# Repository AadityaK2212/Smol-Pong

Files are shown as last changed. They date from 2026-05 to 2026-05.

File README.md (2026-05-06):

# Smol-Pong
It is a mini console that can run a 2 player pong game using a coin cell battery and a 8X8 LED grid. ioriginally saw someoemake a smal buiness card that can play video games, so I elaborated off of that and made it to only play pong I also created one for flappy bird. It runs on an ATtiny 1616 Microcontroller.






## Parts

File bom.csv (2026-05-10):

Designator | Footprint | Quantity | Value | LCSC Part #
BT1 | BatteryHolder_Keystone_1057_1x2032 | 1 | Battery_Cell
D1, D10, D11, D12, D13, D14, D15, D16, D17, D18, D19, D2, D20, D21, D22, D23, D24, D25, D26, D27, D28, D29, D3, D30, D31, D32, D33, D34, D35, D36, D37, D38, D39, D4, D40, D41, D42, D43, D44, D45, D46, D47, D48, D49, D5, D50, D51, D52, D53, D54, D55, D56, D57, D58, D59, D6, D60, D61, D62, D63, D64, D7, D8, D9 | 0603 | 64 | LED
R1, R13, R14, R15, R16, R17, R18, R19, R2, R20, R3, R4, R5, R6, R7, R8 | 0603 | 16 | 100 Ω
SW1 | SW_SPST_TL3342 | 1 | SW_P1_UP
U1 | VQFN-20-1EP_3x3mm_P0.4mm_EP1.7x1.7mm | 1 | ATtiny1616-M

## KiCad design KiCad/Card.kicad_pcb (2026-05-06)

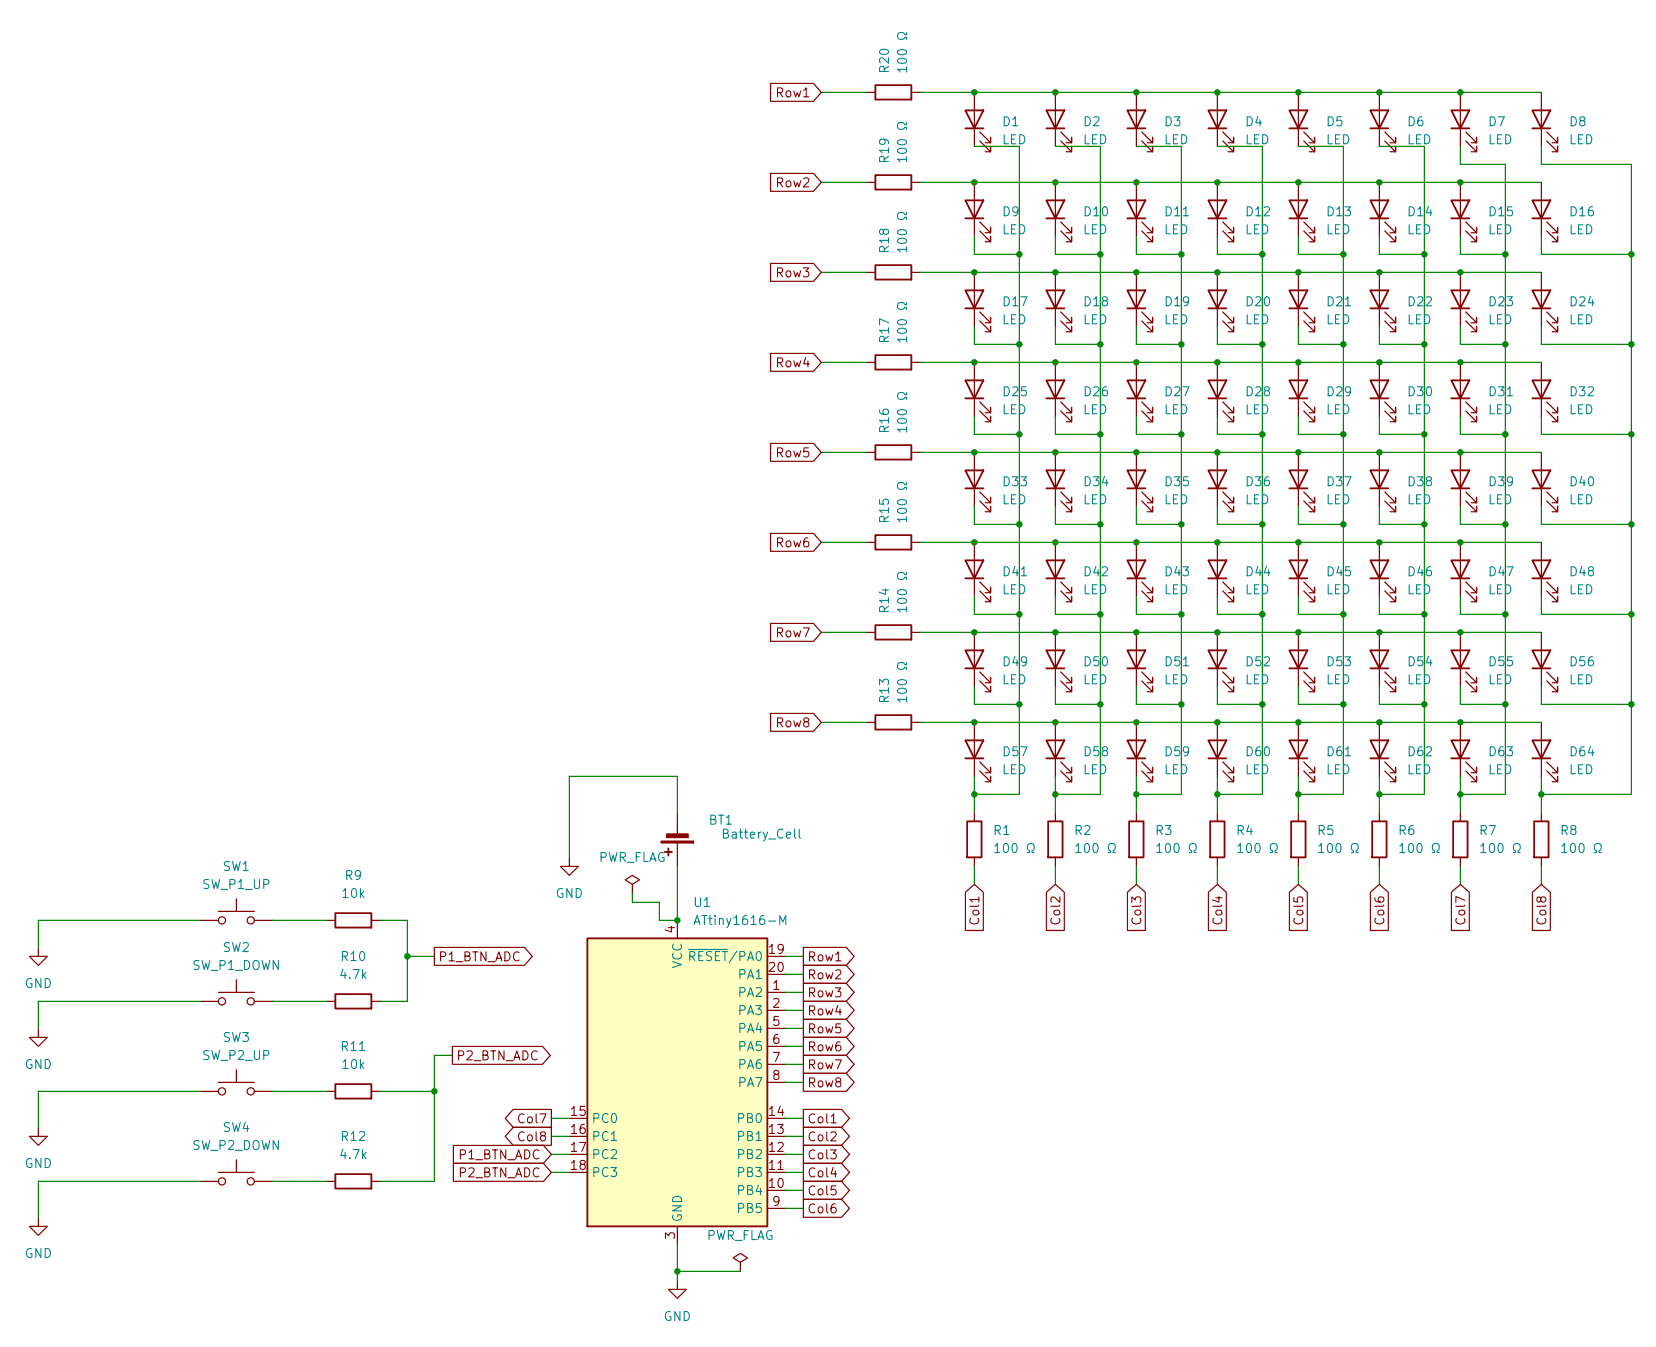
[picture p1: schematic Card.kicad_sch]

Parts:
BT1: Battery_Cell; BatteryHolder_Keystone_1057_1x2032
D1, D2, D3, D4, D5, D6, D7, D8, D9, D10, D11, D12, D13, D14, D15, D16, D17, D18, D19, D20, D21, D22, D23, D24, D25, D26, D27, D28, D29, D30, D31, D32, D33, D34, D35, D36, D37, D38, D39, D40, D41, D42, D43, D44, D45, D46, D47, D48, D49, D50, D51, D52, D53, D54, D55, D56, D57, D58, D59, D60, D61, D62, D63, D64: LED; LED_0603_1608Metric
R1, R2, R3, R4, R5, R6, R7, R8, R13, R14, R15, R16, R17, R18, R19, R20: 100 Ω; R_0603_1608Metric
R9, R11: 10k; R_0603_1608Metric
R10, R12: 4.7k; R_0603_1608Metric
SW1: SW_P1_UP; SW_SPST_TL3342
SW2: SW_P1_DOWN; SW_SPST_TL3342
SW3: SW_P2_UP; SW_SPST_TL3342
SW4: SW_P2_DOWN; SW_SPST_TL3342
U1: ATtiny1616-M; VQFN-20-1EP_3x3mm_P0.4mm_EP1.7x1.7mm

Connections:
Col1: R1.2, U1.14 (PB0)
Col2: R2.2, U1.13 (PB1)
Col3: R3.2, U1.12 (PB2)
Col4: R4.2, U1.11 (PB3)
Col5: R5.2, U1.10 (PB4)
Col6: R6.2, U1.9 (PB5)
Col7: R7.2, U1.15 (PC0)
Col8: R8.2, U1.16 (PC1)
GND: BT1.2 (-), SW1.1, SW2.1, SW3.1, SW4.1, U1.3 (GND), U1.21 (GND)
unnamed: BT1.1 (+), U1.4 (VCC)
unnamed: D1.2 (A), D2.2 (A), D3.2 (A), D4.2 (A), D5.2 (A), D6.2 (A), D7.2 (A), D8.2 (A), R20.2
unnamed: D1.1 (K), D9.1 (K), D17.1 (K), D25.1 (K), D33.1 (K), D41.1 (K), D49.1 (K), D57.1 (K), R1.1
unnamed: D9.2 (A), D10.2 (A), D11.2 (A), D12.2 (A), D13.2 (A), D14.2 (A), D15.2 (A), D16.2 (A), R19.2
unnamed: D2.1 (K), D10.1 (K), D18.1 (K), D26.1 (K), D34.1 (K), D42.1 (K), D50.1 (K), D58.1 (K), R2.1
unnamed: D3.1 (K), D11.1 (K), D19.1 (K), D27.1 (K), D35.1 (K), D43.1 (K), D51.1 (K), D59.1 (K), R3.1
unnamed: D4.1 (K), D12.1 (K), D20.1 (K), D28.1 (K), D36.1 (K), D44.1 (K), D52.1 (K), D60.1 (K), R4.1
unnamed: D5.1 (K), D13.1 (K), D21.1 (K), D29.1 (K), D37.1 (K), D45.1 (K), D53.1 (K), D61.1 (K), R5.1
unnamed: D6.1 (K), D14.1 (K), D22.1 (K), D30.1 (K), D38.1 (K), D46.1 (K), D54.1 (K), D62.1 (K), R6.1
unnamed: D7.1 (K), D15.1 (K), D23.1 (K), D31.1 (K), D39.1 (K), D47.1 (K), D55.1 (K), D63.1 (K), R7.1
unnamed: D8.1 (K), D16.1 (K), D24.1 (K), D32.1 (K), D40.1 (K), D48.1 (K), D56.1 (K), D64.1 (K), R8.1
unnamed: D17.2 (A), D18.2 (A), D19.2 (A), D20.2 (A), D21.2 (A), D22.2 (A), D23.2 (A), D24.2 (A), R18.2
unnamed: D25.2 (A), D26.2 (A), D27.2 (A), D28.2 (A), D29.2 (A), D30.2 (A), D31.2 (A), D32.2 (A), R17.2
unnamed: D33.2 (A), D34.2 (A), D35.2 (A), D36.2 (A), D37.2 (A), D38.2 (A), D39.2 (A), D40.2 (A), R16.2
unnamed: D41.2 (A), D42.2 (A), D43.2 (A), D44.2 (A), D45.2 (A), D46.2 (A), D47.2 (A), D48.2 (A), R15.2
unnamed: D49.2 (A), D50.2 (A), D51.2 (A), D52.2 (A), D53.2 (A), D54.2 (A), D55.2 (A), D56.2 (A), R14.2
unnamed: D57.2 (A), D58.2 (A), D59.2 (A), D60.2 (A), D61.2 (A), D62.2 (A), D63.2 (A), D64.2 (A), R13.2
unnamed: R9.1, SW1.2
unnamed: R10.1, SW2.2
unnamed: R11.1, SW3.2
unnamed: R12.1, SW4.2
P1_BTN_ADC: R9.2, R10.2, U1.17 (PC2)
P2_BTN_ADC: R11.2, R12.2, U1.18 (PC3)
Row1: R20.1, U1.19 (~RESET/PA0)
Row2: R19.1, U1.20 (PA1)
Row3: R18.1, U1.1 (PA2)
Row4: R17.1, U1.2 (PA3)
Row5: R16.1, U1.5 (PA4)
Row6: R15.1, U1.6 (PA5)
Row7: R14.1, U1.7 (PA6)
Row8: R13.1, U1.8 (PA7)

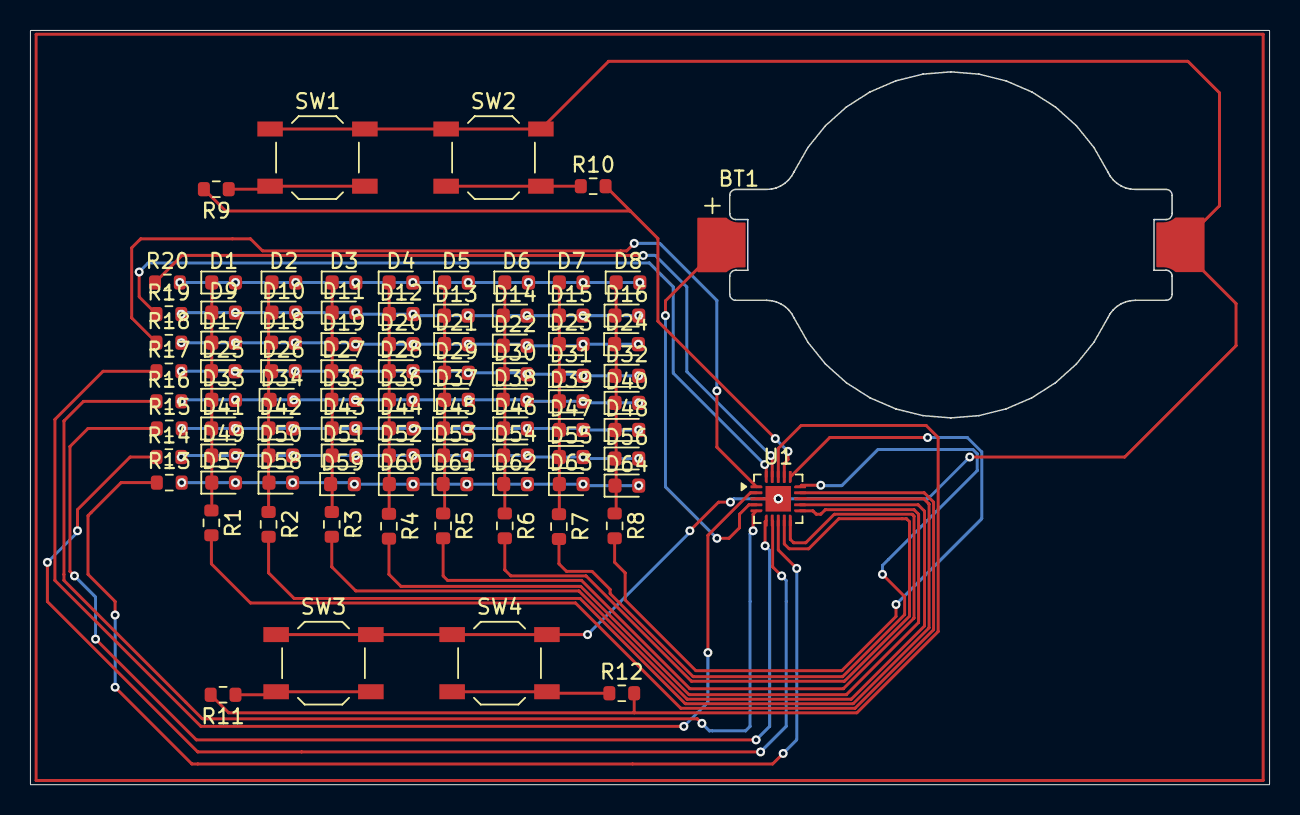
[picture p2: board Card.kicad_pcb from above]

Board: 2 copper layers, 82.4 x 50.1 mm, 90 parts (0 on the bottom side), 40 nets.

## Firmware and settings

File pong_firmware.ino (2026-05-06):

// Pong on an 8x8 LED matrix, driven by an ATtiny1616.
// Two players, two buttons each (UP / DOWN), wired as an analog
// resistor ladder so each player only burns one MCU pin.
//
// Hardware notes (from the schematic):
//   - Rows  -> PA0..PA7  (Row1..Row8) -- these are the LED CATHODES
//   - Cols  -> PB0..PB5  (Col1..Col6)
//             PC0 -> Col7
//             PC1 -> Col8                -- columns are the LED ANODES
//   - PC2   -> P1 button ADC node
//   - PC3   -> P2 button ADC node
//
// To light pixel (row, col): drive that column HIGH, that row LOW,
// every other row Hi-Z (or HIGH), every other column LOW.
// We multiplex one column at a time at a few hundred Hz so the whole
// frame looks stable to the eye.
//
// Button decoding:
//   Idle (nothing pressed) the ADC pin floats up to ~VCC through the
//   internal pull-up. Pressing UP shorts it through 10k to GND, pressing
//   DOWN shorts it through 4.7k to GND. With the ATtiny's ~30-50k
//   internal pull-up that gives roughly:
//       idle  -> ~1023
//       UP    -> ~250-350
//       DOWN  -> ~120-180
//   We just pick two thresholds with comfortable margin.

#include <Arduino.h>

// ---------- pin map ----------
static const uint8_t ROW_PINS[8] = {
  PIN_PA0, PIN_PA1, PIN_PA2, PIN_PA3,
  PIN_PA4, PIN_PA5, PIN_PA6, PIN_PA7
};
static const uint8_t COL_PINS[8] = {
  PIN_PB0, PIN_PB1, PIN_PB2, PIN_PB3,
  PIN_PB4, PIN_PB5, PIN_PC0, PIN_PC1
};

static const uint8_t P1_ADC_PIN = PIN_PC2;
static const uint8_t P2_ADC_PIN = PIN_PC3;

// ---------- ADC thresholds for the resistor-ladder buttons ----------
// Anything below DOWN_MAX -> down, between -> up, above -> nothing.
// Tweak if your particular pull-up reads differently.
static const uint16_t DOWN_MAX = 220;   // 4.7k pull-down
static const uint16_t UP_MAX   = 500;   // 10k  pull-down
// (>UP_MAX is treated as "no press")

// ---------- framebuffer ----------
// frame[col] is a bitmask of which rows are lit in that column.
// Bit r set -> row r is lit when we light up that column.
static volatile uint8_t frame[8];

// ---------- game state ----------
static const uint8_t PADDLE_LEN = 3;     // pixels tall
static int8_t  p1_y = 3;                 // top row of P1 paddle (col 0)
static int8_t  p2_y = 3;                 // top row of P2 paddle (col 7)

// Ball, stored in 1/8-pixel units so we can have fractional speeds.
// A whole pixel is 8 sub-units.
static int16_t ball_x = 4 * 8;
static int16_t ball_y = 4 * 8;
static int16_t ball_vx = -2;             // sub-units per tick
static int16_t ball_vy =  1;

static uint8_t p1_score = 0;
static uint8_t p2_score = 0;
static const uint8_t WIN_SCORE = 5;

// ---------- timing ----------
static uint32_t last_tick_ms     = 0;
static uint32_t last_input_ms    = 0;
static uint32_t last_repeat_ms[2]= {0, 0};
static const uint16_t TICK_MS    = 90;   // game tick (ball moves about 11 Hz)
static const uint16_t INPUT_MS   = 25;   // poll buttons ~40 Hz
static const uint16_t REPEAT_MS  = 70;   // hold-to-move repeat rate

enum GameMode : uint8_t {
  MODE_PLAY,
  MODE_WIN_P1,
  MODE_WIN_P2,
  MODE_RESET_HOLD
};
static uint8_t mode = MODE_PLAY;
static uint32_t mode_started_ms = 0;

// ===================================================================
// LED MATRIX
// ===================================================================
//
// We park every pin as INPUT (Hi-Z) at start and only drive the pins
// for the column that's currently being shown. That keeps unused
// LEDs fully dark and avoids fighting the ADC pins.

static void matrix_init() {
  for (uint8_t i = 0; i < 8; i++) {
    pinMode(ROW_PINS[i], INPUT);
    pinMode(COL_PINS[i], INPUT);
  }
  for (uint8_t i = 0; i < 8; i++) frame[i] = 0;
}

// Show a single column for a brief moment, then turn it back off.
static void show_column(uint8_t c) {
  uint8_t mask = frame[c];

  // Set every row that should be lit to OUTPUT-LOW (sink current),
  // others to INPUT (Hi-Z).
  for (uint8_t r = 0; r < 8; r++) {
    if (mask & (1 << r)) {
      pinMode(ROW_PINS[r], OUTPUT);
      digitalWrite(ROW_PINS[r], LOW);
    } else {
      pinMode(ROW_PINS[r], INPUT);
    }
  }

  // Drive the chosen column HIGH (source current).
  pinMode(COL_PINS[c], OUTPUT);
  digitalWrite(COL_PINS[c], HIGH);

  // Hold it on. Longer = brighter, but eats CPU time.
  delayMicroseconds(700);

  // Turn the column back off and release the rows.
  digitalWrite(COL_PINS[c], LOW);
  pinMode(COL_PINS[c], INPUT);
  for (uint8_t r = 0; r < 8; r++) {
    if (mask & (1 << r)) pinMode(ROW_PINS[r], INPUT);
  }
}

// Run one full pass over all 8 columns. Call this in a tight loop.
static void refresh_once() {
  for (uint8_t c = 0; c < 8; c++) show_column(c);
}

// Helpers used by the game logic to draw into the framebuffer.
static inline void fb_clear() {
  for (uint8_t c = 0; c < 8; c++) frame[c] = 0;
}
static inline void fb_set(int8_t x, int8_t y) {
  if (x < 0 || x > 7 || y < 0 || y > 7) return;
  frame[x] |= (uint8_t)(1 << y);
}

// ===================================================================
// BUTTONS
// ===================================================================

enum BtnState : uint8_t { BTN_NONE = 0, BTN_UP = 1, BTN_DOWN = 2 };

static uint8_t read_button(uint8_t pin) {
  uint16_t v = analogRead(pin);
  if (v < DOWN_MAX) return BTN_DOWN;
  if (v < UP_MAX)   return BTN_UP;
  return BTN_NONE;
}

static void buttons_init() {
  // Internal pull-up makes the resistor-ladder math work and gives us
  // a clean "nothing pressed -> full scale" reading.
  pinMode(P1_ADC_PIN, INPUT_PULLUP);
  pinMode(P2_ADC_PIN, INPUT_PULLUP);
  analogReadResolution(10);
}

// ===================================================================
// GAME
// ===================================================================

static void reset_ball(int8_t toward_player) {
  ball_x = 4 * 8;
  ball_y = (random(2, 6)) * 8;
  ball_vx = (toward_player == 1) ? -2 : 2;
  ball_vy = (random(0, 2) ? 1 : -1) * (random(1, 3));
}

static void new_game() {
  p1_score = 0;
  p2_score = 0;
  p1_y = 3;
  p2_y = 3;
  mode = MODE_PLAY;
  reset_ball(random(0, 2) ? 1 : 2);
}

static void clamp_paddle(int8_t &y) {
  if (y < 0) y = 0;
  if (y > 8 - PADDLE_LEN) y = 8 - PADDLE_LEN;
}

// Move a paddle in response to a button, with simple repeat-on-hold.
static void handle_player(uint8_t player_idx, uint8_t btn, uint32_t now) {
  if (btn == BTN_NONE) {
    last_repeat_ms[player_idx] = 0;
    return;
  }
  // First press fires immediately; subsequent fires throttled by REPEAT_MS.
  if (last_repeat_ms[player_idx] != 0 &&
      (now - last_repeat_ms[player_idx]) < REPEAT_MS) {
    return;
  }
  last_repeat_ms[player_idx] = now;

  int8_t &y = (player_idx == 0) ? p1_y : p2_y;
  if (btn == BTN_UP)   y--;
  if (btn == BTN_DOWN) y++;
  clamp_paddle(y);
}

static bool paddle_hits(int8_t paddle_y, int8_t bx, int8_t by) {
  // bx is the column adjacent to a paddle wall, by is integer ball row.
  if (bx != 0 && bx != 7) return false;
  return (by >= paddle_y) && (by < paddle_y + PADDLE_LEN);
}

static void physics_tick() {
  ball_x += ball_vx;
  ball_y += ball_vy;

  // Bounce off top/bottom.
  if (ball_y < 0)        { ball_y = 0;        ball_vy = -ball_vy; }
  if (ball_y > 7 * 8)    { ball_y = 7 * 8;    ball_vy = -ball_vy; }

  int8_t bx = ball_x / 8;
  int8_t by = ball_y / 8;

  // Left wall (P1).
  if (ball_x <= 0) {
    if (paddle_hits(p1_y, 0, by)) {
      ball_x = 0;
      ball_vx = -ball_vx;
      // Add a little english based on where it hit the paddle.
      int8_t hit = by - (p1_y + PADDLE_LEN / 2);
      ball_vy += hit;
      if (ball_vy >  3) ball_vy =  3;
      if (ball_vy < -3) ball_vy = -3;
    } else {
      // P2 scores.
      p2_score++;
      if (p2_score >= WIN_SCORE) {
        mode = MODE_WIN_P2;
        mode_started_ms = millis();
      } else {
        reset_ball(1);
      }
    }
  }

  // Right wall (P2).
  if (ball_x >= 7 * 8) {
    if (paddle_hits(p2_y, 7, by)) {
      ball_x = 7 * 8;
      ball_vx = -ball_vx;
      int8_t hit = by - (p2_y + PADDLE_LEN / 2);
      ball_vy += hit;
      if (ball_vy >  3) ball_vy =  3;
      if (ball_vy < -3) ball_vy = -3;
    } else {
      p1_score++;
      if (p1_score >= WIN_SCORE) {
        mode = MODE_WIN_P1;
        mode_started_ms = millis();
      } else {
        reset_ball(2);
      }
    }
  }
}

// ===================================================================
// RENDERING
// ===================================================================

static void render_play() {
  fb_clear();

  // Paddles (column 0 and column 7).
  for (uint8_t i = 0; i < PADDLE_LEN; i++) {
    fb_set(0, p1_y + i);
    fb_set(7, p2_y + i);
  }

  // Ball.
  fb_set(ball_x / 8, ball_y / 8);
}

// Cute little win animation: fill the winner's half of the board,
// then fade it back out, repeat.
static void render_win(uint8_t winner) {
  uint32_t t = millis() - mode_started_ms;
  uint8_t  phase = (t / 150) & 0x07;
  fb_clear();
  if (winner == 1) {
    for (uint8_t c = 0; c <= phase && c < 8; c++) frame[c] = 0xFF;
  } else {
    for (uint8_t c = 0; c < 8; c++) {
      if ((7 - c) <= phase) frame[c] = 0xFF;
    }
  }
  // After ~3 seconds, drop into "hold any button to restart" mode.
  if (t > 3000) mode = MODE_RESET_HOLD;
}

static void render_reset_prompt() {
  // Blink a single dot in the center -- "press anything to play again".
  fb_clear();
  if (((millis() / 400) & 1) == 0) {
    fb_set(3, 3);
    fb_set(4, 3);
    fb_set(3, 4);
    fb_set(4, 4);
  }
}

// ===================================================================
// MAIN
// ===================================================================

void setup() {
  matrix_init();
  buttons_init();
  // Seed the RNG from a floating analog read -- not crypto, just enough
  // to keep the ball from going the same way every power-on.
  randomSeed(analogRead(P1_ADC_PIN) ^ (analogRead(P2_ADC_PIN) << 4) ^ micros());
  new_game();
  last_tick_ms  = millis();
  last_input_ms = millis();
}

void loop() {
  uint32_t now = millis();

  // ---- input ----
  if ((uint32_t)(now - last_input_ms) >= INPUT_MS) {
    last_input_ms = now;
    uint8_t b1 = read_button(P1_ADC_PIN);
    uint8_t b2 = read_button(P2_ADC_PIN);

    if (mode == MODE_PLAY) {
      handle_player(0, b1, now);
      handle_player(1, b2, now);
    } else if (mode == MODE_RESET_HOLD) {
      if (b1 != BTN_NONE || b2 != BTN_NONE) new_game();
    }
  }

  // ---- physics ----
  if (mode == MODE_PLAY && (uint32_t)(now - last_tick_ms) >= TICK_MS) {
    last_tick_ms = now;
    physics_tick();
  }

  // ---- render ----
  switch (mode) {
    case MODE_PLAY:        render_play();          break;
    case MODE_WIN_P1:      render_win(1);          break;
    case MODE_WIN_P2:      render_win(2);          break;
    case MODE_RESET_HOLD:  render_reset_prompt();  break;
  }

  // One pass over the matrix. Call this as often as possible so the
  // display doesn't flicker.
  refresh_once();
}
